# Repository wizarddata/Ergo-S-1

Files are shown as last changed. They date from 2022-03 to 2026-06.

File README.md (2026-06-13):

# Ergo S-1 Wireless Keyboard

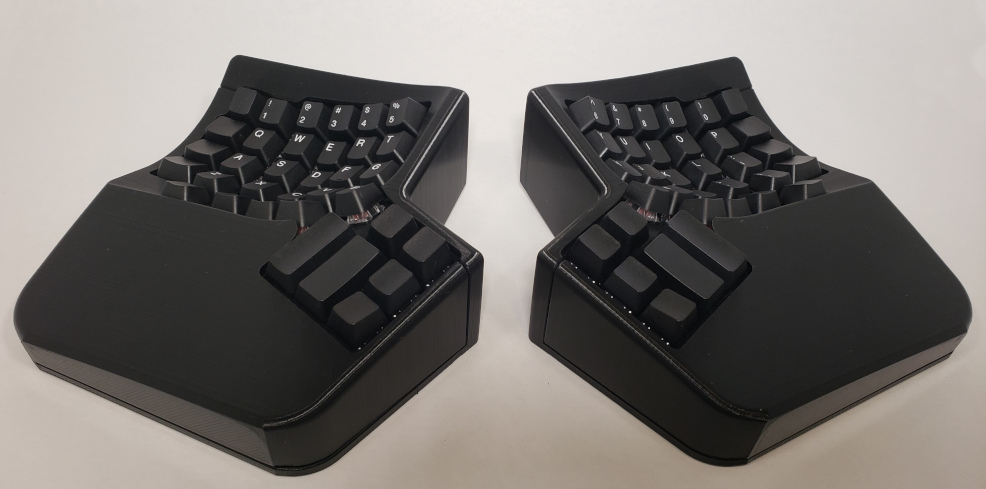
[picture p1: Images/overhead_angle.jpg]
Image_of_Rev0


_Wizard Keyboards Discord_: https://discord.gg/En7Kx4a6tZ

_More Pictures_: https://wizardkeyboards.com/gallery/

_Firmware_: https://github.com/wizarddata/zmk/tree/Ergo_S-1_OE

_Assembly Instructions & BOM_: https://github.com/wizarddata/Ergo-S-1/blob/main/Ergo%20S-1%20OE%20Assembly%20Instructions.pdf

_Customize the keyboard layout_: https://github.com/arcanemachine/zmk-ergo-s-1

_Download the Fusion 360 file_: https://github.com/wizarddata/Ergo-S-1/blob/main/SOURCE/ergo-s-1-oe-rev0-v1.zip

_Other useful stuff (Purchase list, Printable tenting stand, etc.)_: https://github.com/arcanemachine/Ergo-S-1-Extras

_Similar projects and forks_: [Ergo-V-1](https://github.com/VPavliashvili/Ergo-V-1) A wired QMK based version of this keyboard with some modifications

**What Is it?**  
>The Ergo S-1 is a fully wireless, split ergonomic keyboard that is compatible with cherry/gateron switches and cherry/oem/dcs keycaps. It runs on the fantastic ZMK firmware.

**Why Is It?**  
>I love ergonomic keyboards. My first keyboard that I built was an Atreus, and how accessible that was for a beginner stuck with me. While I was unemployed in 2021 I spent my time designing an ergonomic keyboard that would be easy for a anyone to build.  
This is the first step in acheiving that goal. The cases are designed to give you easy access to the switches for hand wiring. There's a parts list included for everything else that you'll need.

**What Switches / Keycaps Can I Use?**  
>This layout was designed to be compatible with standard **cherry/oem 104-key** keycap sets. DCS is also compatible, but DSA or SA will not work on all keys due to the keywell shape.  
This case is compabilbe with **cherry mx and gateron switches**. The switches are held in place by the recess in the sides, so alternate designs like kailh or otemu will not fit.

**Can You Make Me One?**  
>While this case is open source and free for anyone to build on their own, it can be challenging to get the print just right. So I have some available in my Etsy store.  
>https://www.etsy.com/shop/WizardKeyboards

**Do You Make A Complete Kit?**  
>Not yet, but I'm working on it! At this time you need to source switches, keycaps, and electronics from other vendors. I've included links with the recommended hardware list to make this as easy as possible.  
If an (even) easier to assemble kit is something you want, let me know! I'm working as hard as I can to get that done.

**This Is Great! How Can I Help?**  
>The best thing you can do to help me is to share my work! The more popular this design becomes, the easier it will be for me to get to make kits or even assembled keyboards.

**Which license is this project released under?**
>The hardware and associated documentation is released under CERN OHL-S v2. Full license text is available in the SOURCE folder.  
>OSHWA UID US002119

**How can I build my own custom firmware with a customized keymap?**
>Follow the instructions at this repo: https://github.com/arcanemachine/zmk-ergo-s-1  
>OR use https://github.com/wizarddata/ergo-s1-zmk-webbuilder

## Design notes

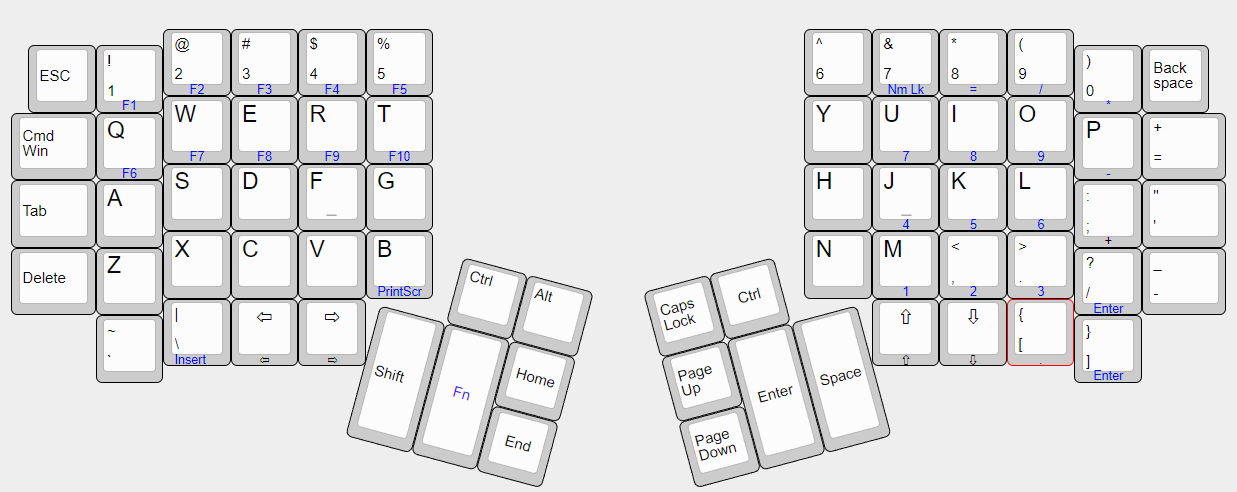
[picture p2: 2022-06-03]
Ergo_S-1_Layout.png

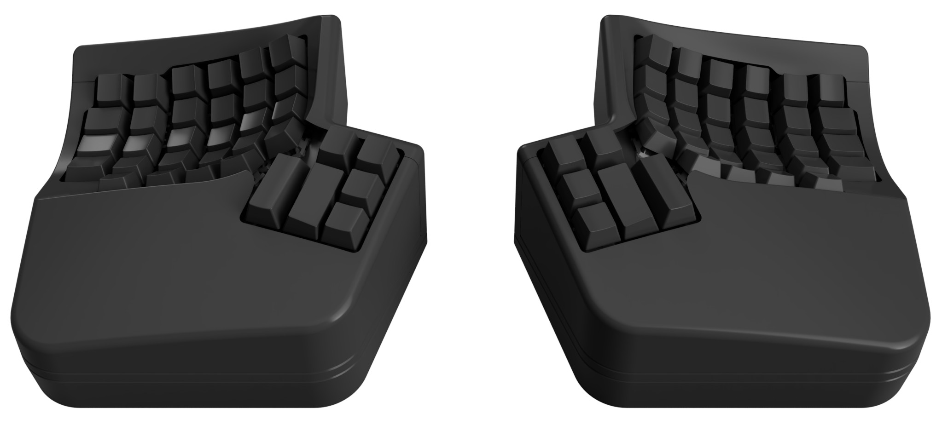
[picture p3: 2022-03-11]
Images/render.jpg

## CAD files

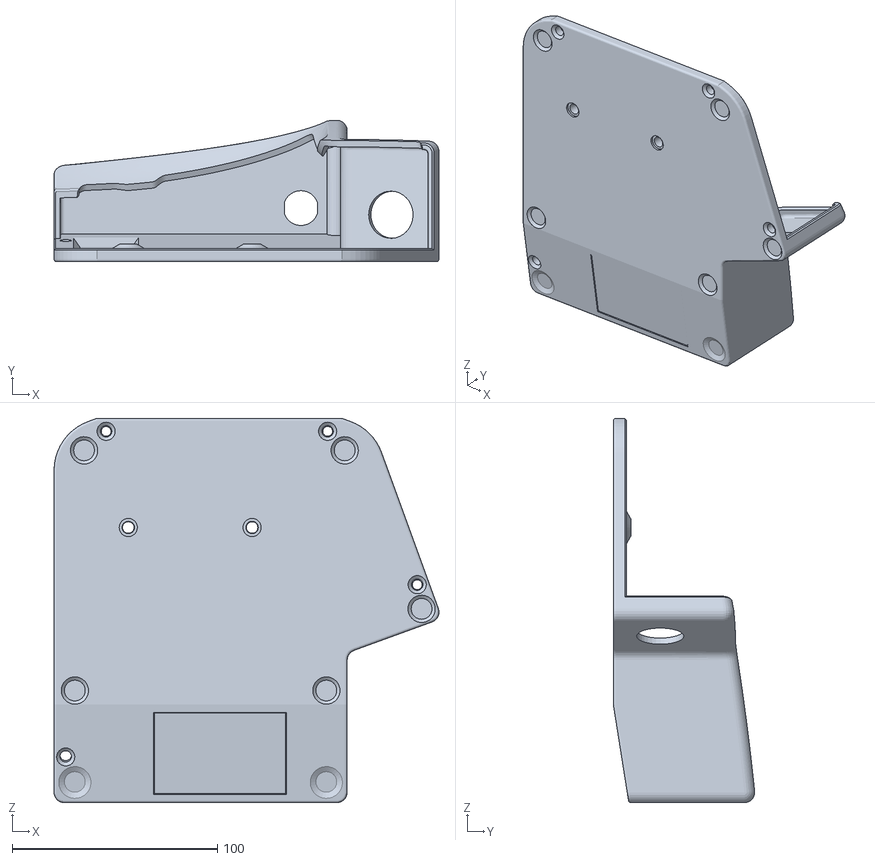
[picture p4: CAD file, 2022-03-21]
STL/Base_Left.stl
187.6 x 68.9 x 187.3

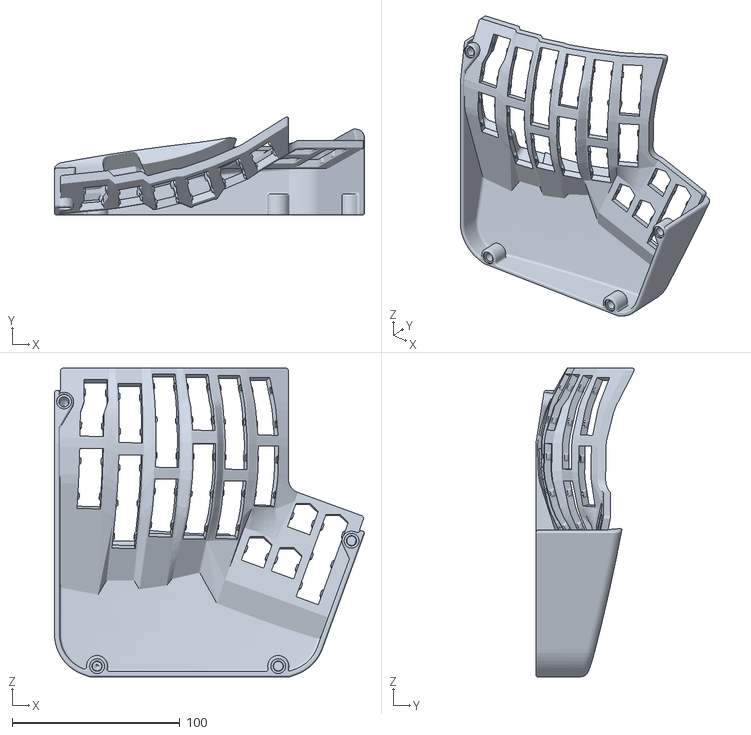
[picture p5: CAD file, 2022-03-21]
STL/Keywell_Right.stl
184.7 x 58.6 x 183.9

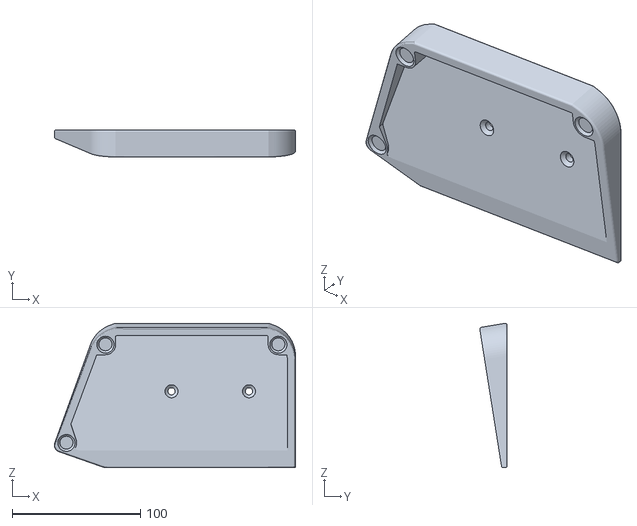
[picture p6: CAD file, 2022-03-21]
STL/Ramp_Right.stl
187.6 x 21.3 x 112.5

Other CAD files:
STL/Ramp_Left.stl
STL/Base_Right.stl
STL/Keywell_Left.stl

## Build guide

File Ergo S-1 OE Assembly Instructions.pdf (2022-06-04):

# Ergo S-1 OE – Assembly Instructions

Wizard Keyboards | 1

Table of Contents

Wizard Keyboards | 2

### 1. What You’ll Need

- Left and Right Cases | https://github.com/wizarddata/Ergo-S-1
- (Optional) Left and Right Ramp | https://github.com/wizarddata/Ergo-S-1
- 12x M4 Heat Set Inserts | https://www.mcmaster.com/94180A351
- 12x M4 Bolts | https://www.mcmaster.com/92010A222/
- 10x Silicone Adhesive Feet | https://www.mcmaster.com/95495K57/
- 68x Cherry / Gateron Switches
- Cherry/OEM/DCS 104-Key Keycap Set
- 68x Diodes | 1N4148
- Insulated Wire | Stranded 30ga silicone insulation
- 2x Wireless Microcontrollers | https://zmk.dev/docs/hardware/
- 2x Panel Mount USB-C | https://www.adafruit.com/product/4218
- 2x Panel Mount Reset Switch | https://www.adafruit.com/product/1505
- 2x Battery | https://www.sparkfun.com/products/13855
- Soldering Iron
- Hot Glue Gun
- Double Sided Tape

Cases, Ramps, Heat Set Inserts, Bolts and Silicone Feet are available in my Etsy store: https://www.etsy.com/shop/WizardKeyboards

### 2. Compatibility

### 2.1. Switch / Keycap Compatibility

This layout was designed to be compatible with standard Cherry/OEM 104-key keycap sets. DCS is also compatible, but DSA or SA will not work on all keys due to the keywell shape.
The case is compatible with Cherry Mx and Gateron switches. The switches are held in place by the recess in the sides, so alternate designs like Kailh or Otemu will not fit.

### 2.2. Insulated Wire

For this guide, stranded 30ga silicone insulated wire was used. Some people prefer enameled magnet wire.

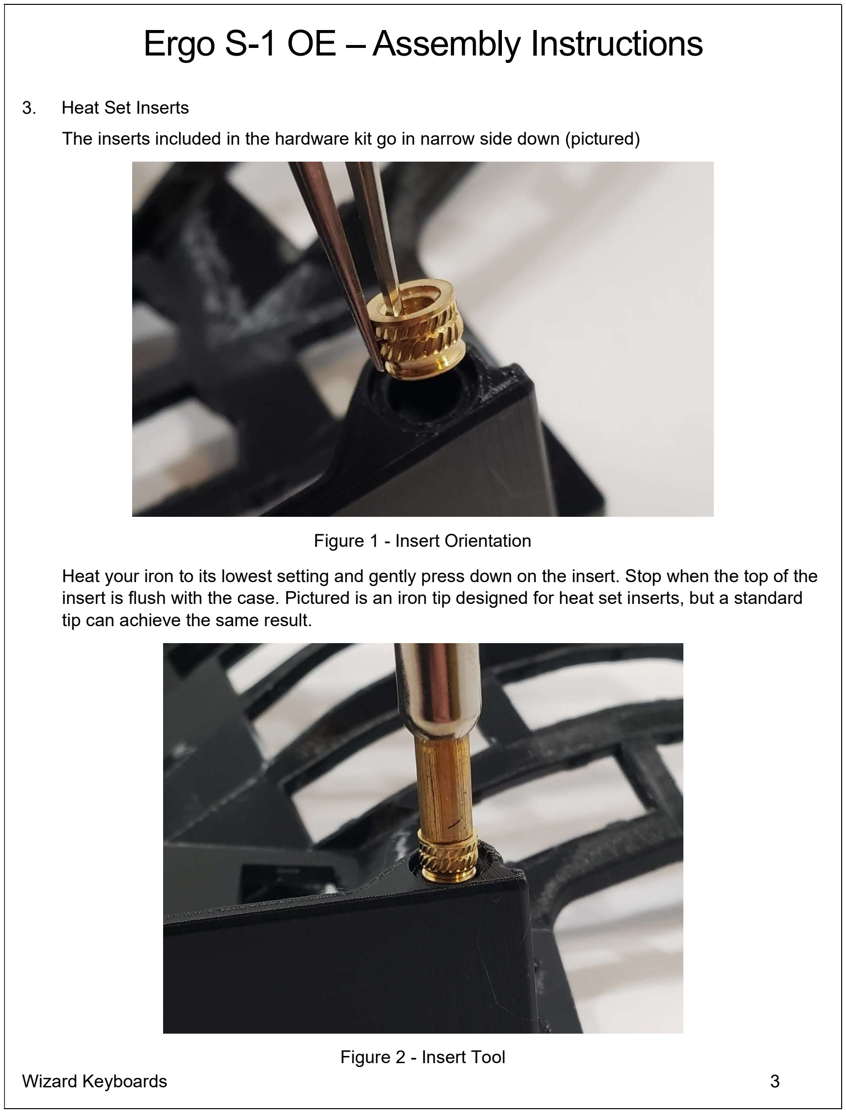
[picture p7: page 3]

Wizard Keyboards | 3

### 3. Heat Set Inserts

The inserts included in the hardware kit go in narrow side down (pictured)

Figure 1 - Insert Orientation

Heat your iron to its lowest setting and gently press down on the insert. Stop when the top of the insert is flush with the case. Pictured is an iron tip designed for heat set inserts, but a standard tip can achieve the same result.

Figure 2 - Insert Tool

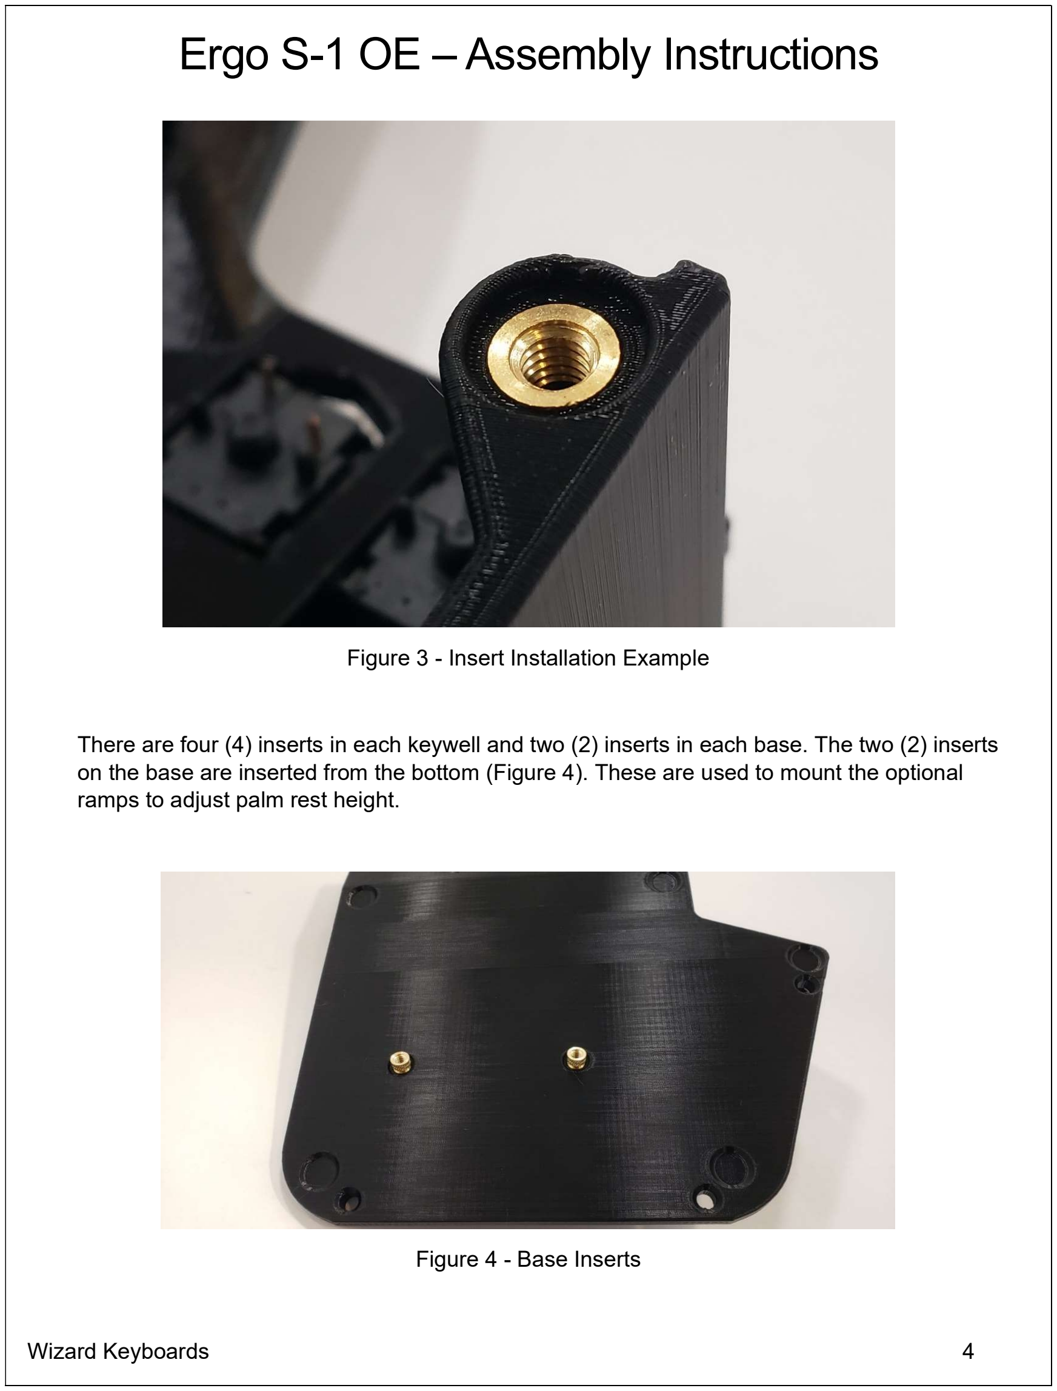
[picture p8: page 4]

Wizard Keyboards | 4

Figure 3 - Insert Installation Example

There are four (4) inserts in each keywell and two (2) inserts in each base. The two (2) inserts on the base are inserted from the bottom (Figure 4). These are used to mount the optional ramps to adjust palm rest height.

Figure 4 - Base Inserts

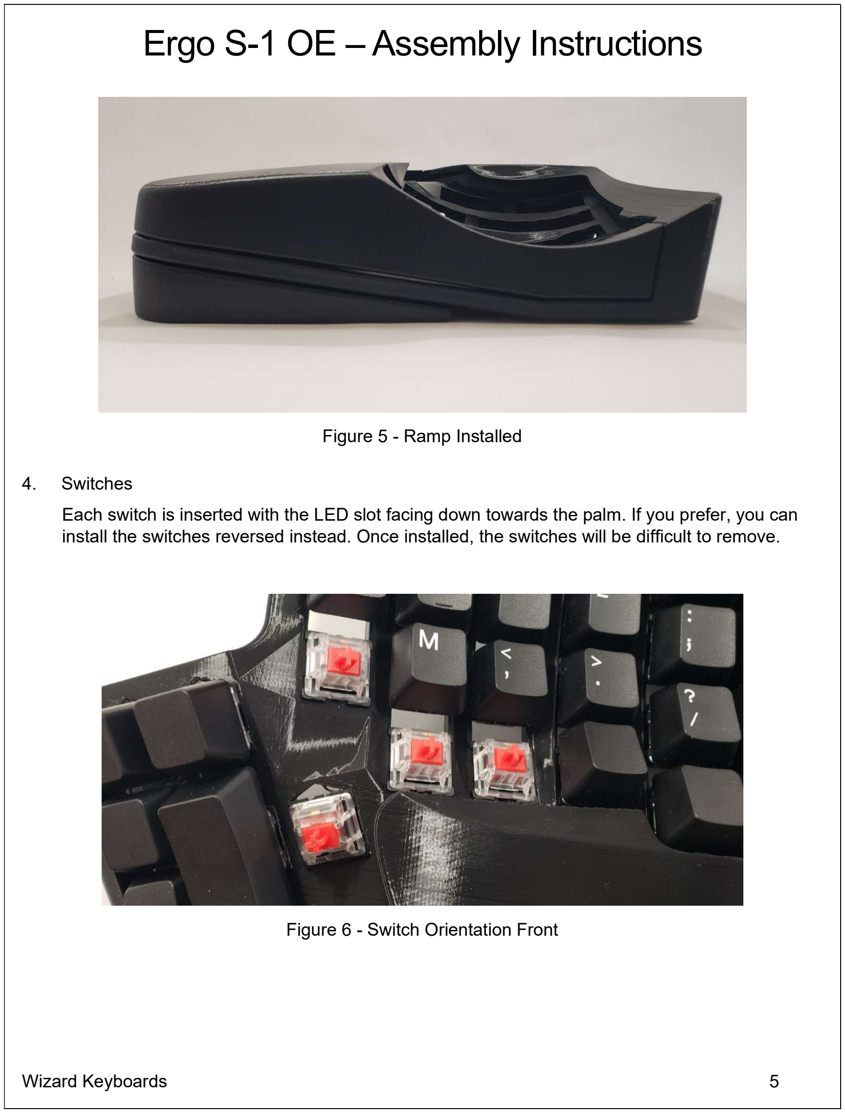
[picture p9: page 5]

Wizard Keyboards | 5

Figure 5 - Ramp Installed

### 4. Switches

Each switch is inserted with the LED slot facing down towards the palm. If you prefer, you can install the switches reversed instead. Once installed, the switches will be difficult to remove.

Figure 6 - Switch Orientation Front

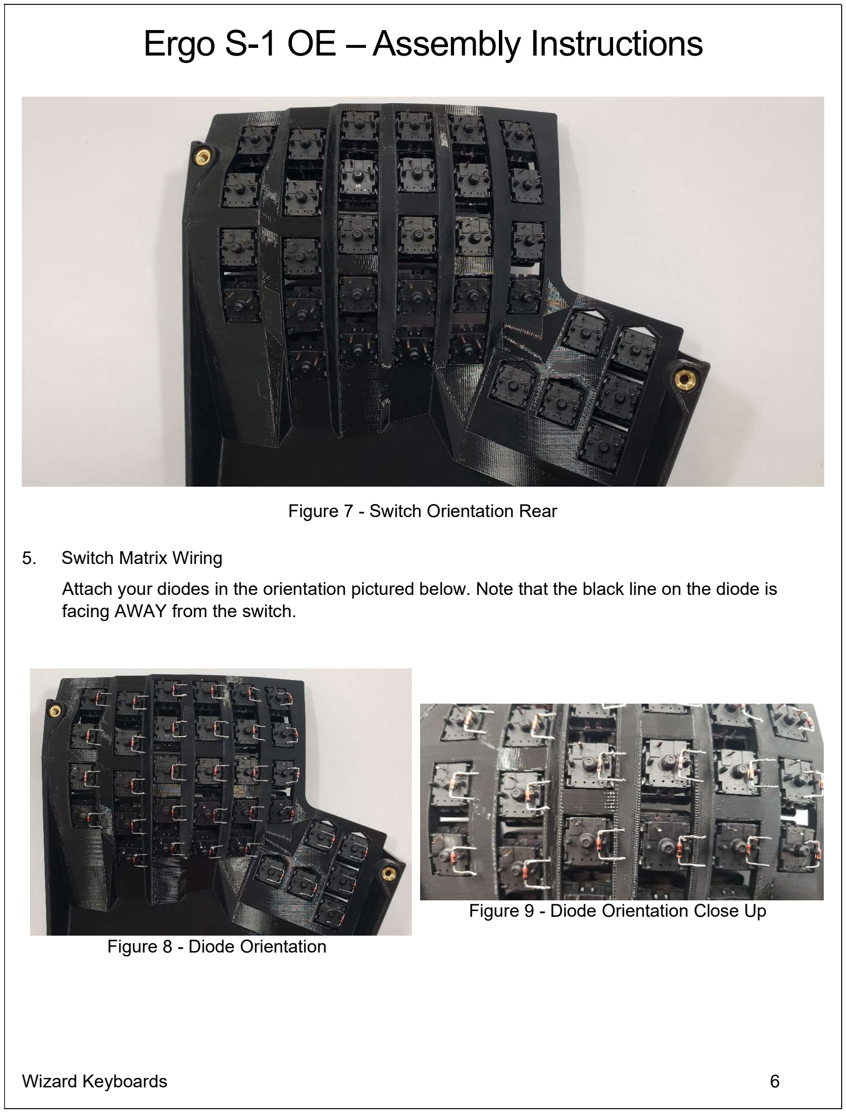
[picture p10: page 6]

Wizard Keyboards | 6

Figure 7 - Switch Orientation Rear

### 5. Switch Matrix Wiring

Attach your diodes in the orientation pictured below. Note that the black line on the diode is facing AWAY from the switch.

Figure 8 - Diode Orientation

Figure 9 - Diode Orientation Close Up

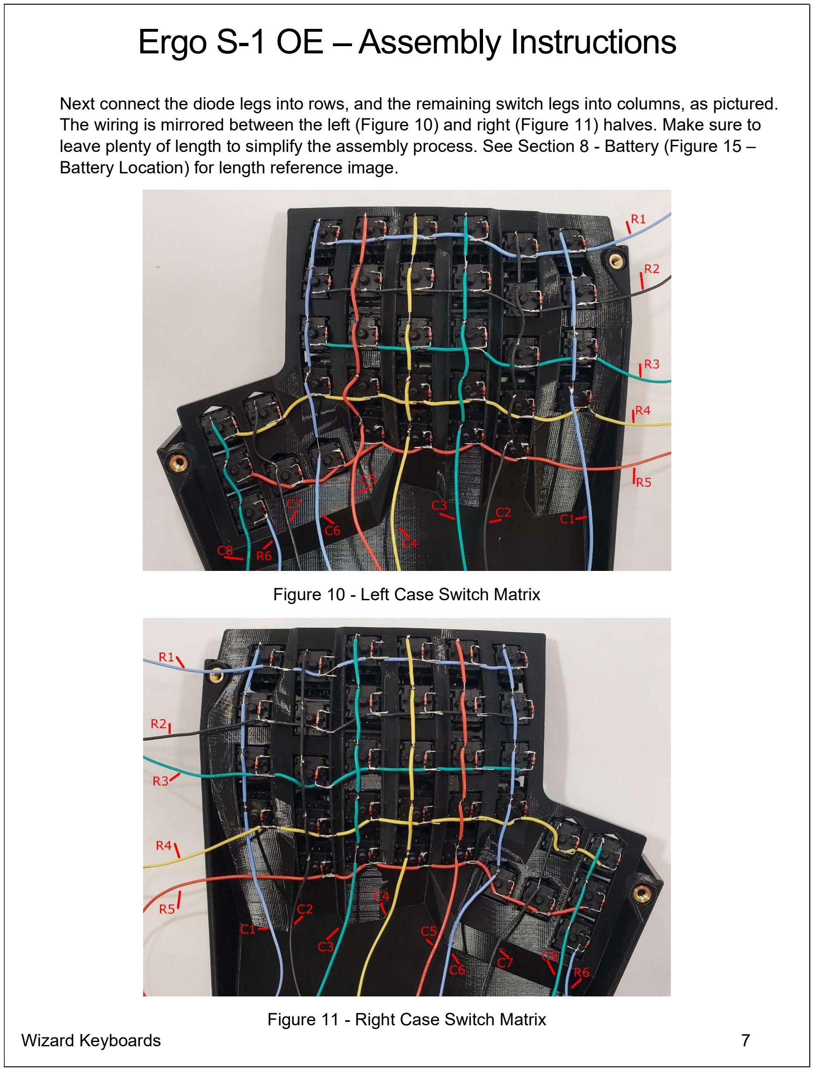
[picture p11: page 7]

Wizard Keyboards | 7

Next connect the diode legs into rows, and the remaining switch legs into columns, as pictured. The wiring is mirrored between the left (Figure 10) and right (Figure 11) halves. Make sure to leave plenty of length to simplify the assembly process. See Section 8 - Battery (Figure 15 – Battery Location) for length reference image.

Figure 10 - Left Case Switch Matrix

Figure 11 - Right Case Switch Matrix

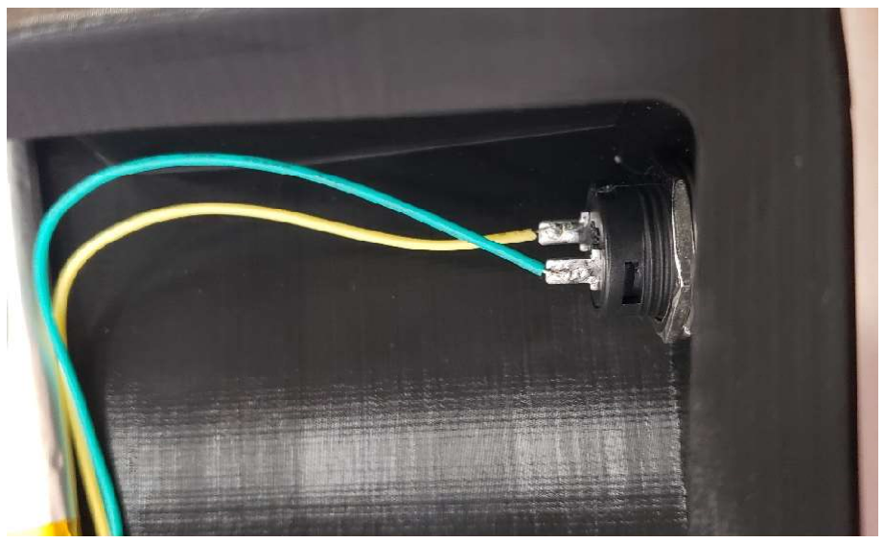
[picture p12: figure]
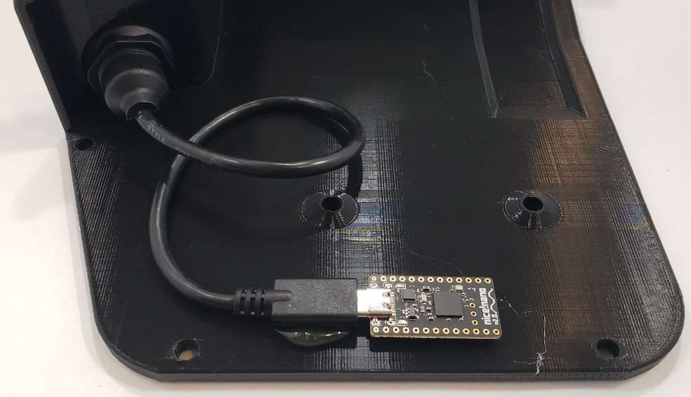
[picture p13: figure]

Wizard Keyboards | 8

### 6. Reset Switch

Connect each leg of the reset switch to a wire as shown below. One will connect to your microcontroller’s RESET pin, the other will connect to GND.

Figure 12 - Reset Switch

### 7. Microcontroller

For this guide, a nice!nano microcontroller was used. Other good options are the nRFMicro or BlueMicro840. For any alternatives, you’ll need to update your firmware configuration as each model has a different pinout.
For a complete list of ZMK’s supported hardware: https://zmk.dev/docs/hardware
Hot glue the male end of the panel mount USB connector to this area of the case. Do not glue the micro controller down, you’ll need to be able to remove it to connect the switch matrix wiring and possibly for future diagnostics.

Figure 13 - Microcontroller Location

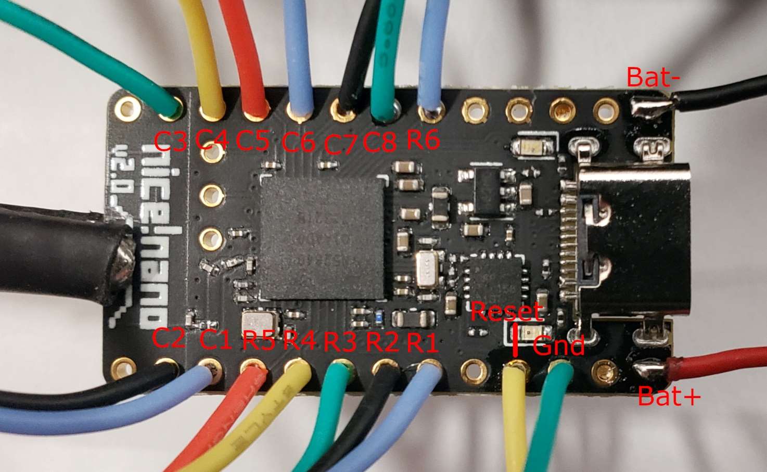
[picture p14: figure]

Wizard Keyboards | 9

### 7.1. Microcontroller Wiring

Wire in the switch matrix to your micro controller according to the diagram below. Also shown, for reference, is a table correlating matrix rows/columns to nice!nano pin labels. Table 1 - Matrix Positions / Pin Labels

Matrix Position | Pin Label
R1 | 031
R2 | 029
R3 | 002
R4 | 115
R5 | 113
R6 | 017
C1 | 111
C2 | 010
C3 | 104
C4 | 011
C5 | 100
C6 | 024
C7 | 022
C8 | 020

Figure 14 - Nice!Nano Wiring

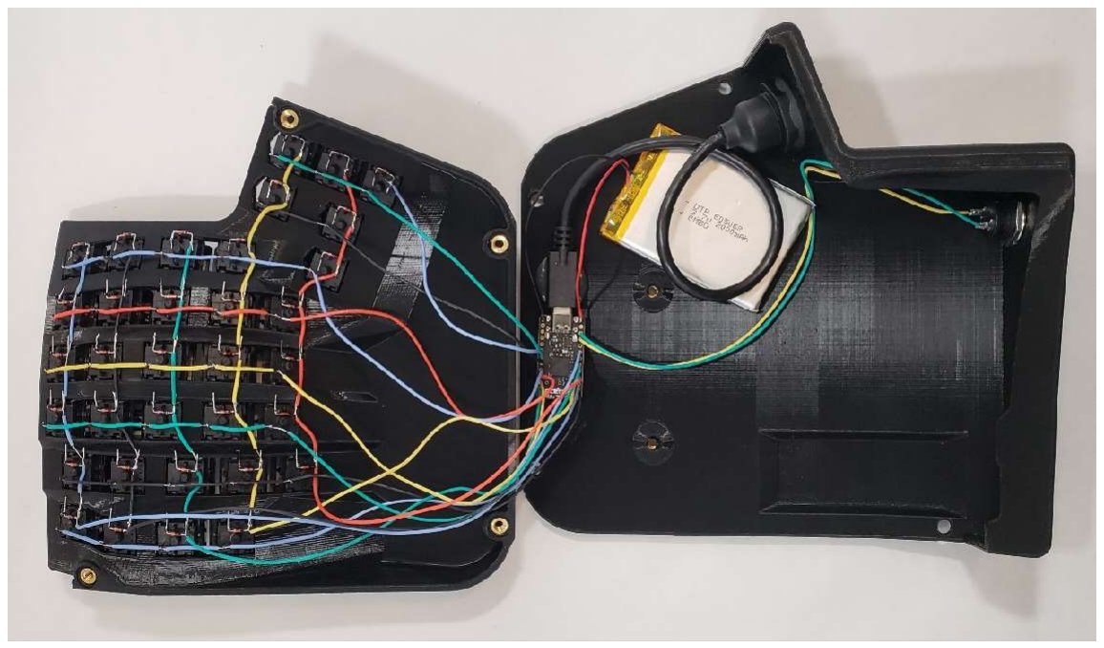
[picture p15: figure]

Wizard Keyboards | 10

### 8. Battery

Attach the battery in this area of the case. Double sided tape is recommended.

Figure 15 - Battery Location

### 9. Firmware

Pre-compiled firmware is available here: https://github.com/wizarddata/Ergo-S-1

Refer to nice!nano documentation for flashing procedure. https://nicekeyboards.com/docs/nice-nano/getting-started/

Refer to ZMK documentation for making layout changes. https://zmk.dev/docs

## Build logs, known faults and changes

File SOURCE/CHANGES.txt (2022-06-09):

Anyone modifying the design should provide brief information about the modifications,
including the date they were made.

Information about the design should be added but never removed from that file. 

According to section 3.3.b of the licence, licensees should
provide a brief entry with a date and the nature of the modification for
each design change. For example ‘26 April 2020: AC/DC power converter circuit removed as AC input no longer necessary’.

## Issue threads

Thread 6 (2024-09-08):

Repo with extra info (purchase list, customizable parts, etc.)

arcanemachine, 2024-09-08:
This may be useful for anyone who is looking to build an Ergo S-1 but does not live in the United States.

I made a repo which has some extra purchase list information. It adds info like pictures, backup links, alternative links, etc. which may be useful if link rot occurs for the links in the official assembly docs' purchase list.

I am also planning to add some customizability for anyone who ends up buying some alternative parts. Some parts (e.g. adhesive rubber bumpers, USB-C panel mount) may not fit the default STL provided, so I want to provide a path forward for those who have bought parts that aren't in the official assembly docs.

If you are planning to build an Ergo S-1, check out the following repo, especially if you are outside the USA:

https://github.com/arcanemachine/Ergo-S-1

Closed 2024-09-08.

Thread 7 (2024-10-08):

Fusion360 model is undownloadable.

gdianaty, 2024-10-08:
Hello. Cool project!

I cannot download the Fusion360 model, but I can view it in-browser. Is this intended? Is this because of Fusion360 restricting downloads to a pro version?

wizarddata, 2024-10-08:
I don't have the slightest idea. That wasn't deliberate but Fusion has changed a lot since I worked on this model.

gdianaty, 2024-10-09:
Fair enough. Could you can log into Fusion 3D, export the model and upload it to Git via Git LFS? That is, presuming that the Fusion 360 model contains more data than the STEP file.

I'm trying to edit the layout of the board slightly. Looking to post my changes on GitHub as a fork if I'm successful.

wizarddata, 2024-10-10:
I'll look into it, but if I remember correctly I shared it this way for some specific reason. Maybe the file was too large for GitHub.

gdianaty, 2024-10-10:
Perhaps! If that is the case -- perhaps Git LFS would be an adequate solution? Or uploading it as a GitHub Release file?

Thanks for looking into it. Let me know if I can be of assistance somehow.

wizarddata, 2024-10-13:
Looks like Autodesk did specifically move the ability to download shared models behind their subscription.

I'll look into the options you mentioned.

arcanemachine, 2024-10-13:
@wizarddata If you have a copy of the files you can upload somewhere (like a Google Drive link or some file-sharing site), I have [a repo](https://github.com/arcanemachine/Ergo-S-1-Extras) I could stick them in (I'm sure I can find a way to work around the file size limit or whatever) until you can find a proper solution to bundle them into this repo.

gdianaty, 2024-10-14:
The idea suggested by @arcanemachine is excellent! I'm thinking that could be good. Whatever way works, but Git LFS is probably the best bet overall.

wizarddata, 2024-10-29:
I'm really glad that you've asked me for this model. All this time I was sure that I had made a backup of the final design, but it turns out that was lost to the ether. Who knows how long until Fusion no longer allows you to save your designs locally at all.

https://drive.google.com/file/d/1yzW32YSWRDu7C5iZ5AZJsvdfmKTxLP9M/view?usp=drive_link

@arcanemachine If you would host this model in your repo for now that would be excellent. I'm not much of a software guy, so I have to psyche myself up before I learn something new like LFS.

arcanemachine, 2024-10-30:
The original file (101.5 MB) was just a bit above the maximum allowed file size on GitHub (100 MB), so I just put it in a zip file to get it just under the limit (99.9 MB). :nerd_face:

I don't have Fusion 360 on my computer at the moment, but the sha256sum hash of the original file that I downloaded is `9e36e67b312a6075e69aabc0c31e7a0e32fda713c4426cdff052d63fafdb0930`. I zipped the file, uploaded it to GitHub, downloaded the zip, and pulled the `f3d` file out of the zip, and the hash matched. So it should be good to go.

@gdianaty Can you download the file from my repo and check if it works?

https://github.com/arcanemachine/Ergo-S-1-Extras/blob/main/SOURCE/ergo-s-1-oe-rev0-v1.zip

gdianaty, 2024-10-30:
F3D file obtained, and SHA256 matches. Good idea on the ZIP compression!

wizarddata, 2024-10-31:
I wish you all the luck in the world trying to work through this model's timeline.

gdianaty, 2024-11-02:
I already went on my medium-sized timeline adventure, extracted the
relevant sketches and made the appropriate edits in Inventor. Now I just
need to find an opportunity to print it! lol

It's unrelated to the ticket but I'll share what I'm up to -- I'm removing
the 2.25u buttons from the thumb cluster and replacing them with normal
ones. Just a preference thing!

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

--
Thanks,
<https://gmdianaty.com/>
Graham Dianaty <https://gmdianaty.com/>

wizarddata, 2024-11-03:
That's awesome. Hit up the discord and post some pictures!

gdianaty, 2024-11-04:
> That's awesome. Hit up the discord and post some pictures!

Totally! Where can I join?

wizarddata, 2024-11-04:
https://discord.gg/Vd6BWgzV

Closed 2024-10-31.

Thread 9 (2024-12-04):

Can i have your flexible PCB PCB design file please?

weekinro, 2024-12-04:
https://hackaday.com/2022/08/10/from-product-to-burnout-to-open-source-the-ergo-s-1-keyboard-story/
I saw that there is a matching flexible PCB in this article. Can I ask you for a design file of the flexible PCB? I want to modify your design file to make a hot-swappable PCB.

weekinro, 2024-12-04:
> 柔性 PCB 设计需要一些改进，使用 5-6 个月后，线路完整性出现了问题。为了实现热插拔，您需要重新设计开关固定片，以便可以移除开关，并且您需要重新设计机壳的下半部分，以便从下方支撑 PCB，以便可以插入新开关。
>
> 所有这些都表明这种设计确实不适合热插拔，但是如果您想尝试一下，请联系我们的 discord 服务器。

Thank you very much. I have contacted you on Discord and am waiting for your reply，thanks

Closed 2025-05-01.

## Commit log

2022-03-21 BOM separated out
2022-03-21 STLs added
    [Base_Left.stl, Base_Right.stl, Case_Left.stl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]
2022-04-08 Update Parts List - BOM.txt
2022-05-22 renamed models
    [Keywell_Left.stl, Keywell_Right.stl]
2022-06-03 Rev 0 Issue
    Added compiled firmware, assembly guide, and updated layout reference image
2022-06-21 Update README.md
    Added link to Assembly & BOM
